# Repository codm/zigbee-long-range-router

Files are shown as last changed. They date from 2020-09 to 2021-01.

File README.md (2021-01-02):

# cod.m CC2530+CC2592 Long Range ZigBee Router
Here are the Eagle board files and schematic of cod.m's [Zigbee Long Range Router](https://shop.codm.de/automation/zigbee/23/zigbee-cc2530-cc2592-long-range-router/repeater) based on EByte's E18-MS1PA1-IPX sporting an CC2530 combined with an CC2592 PA/LNA for range extension.

The corresponding eagle library for the EByte modules, including 3D models, can be found here: https://github.com/codm/eagle-libraries

You can buy a ready built router, including external antenna, 3D printed case and power supply at our webshop: [CC2530-CC2592 Long Range ZigBee Router](https://shop.codm.de/automation/zigbee/23/zigbee-cc2530-cc2592-long-range-router/repeater)

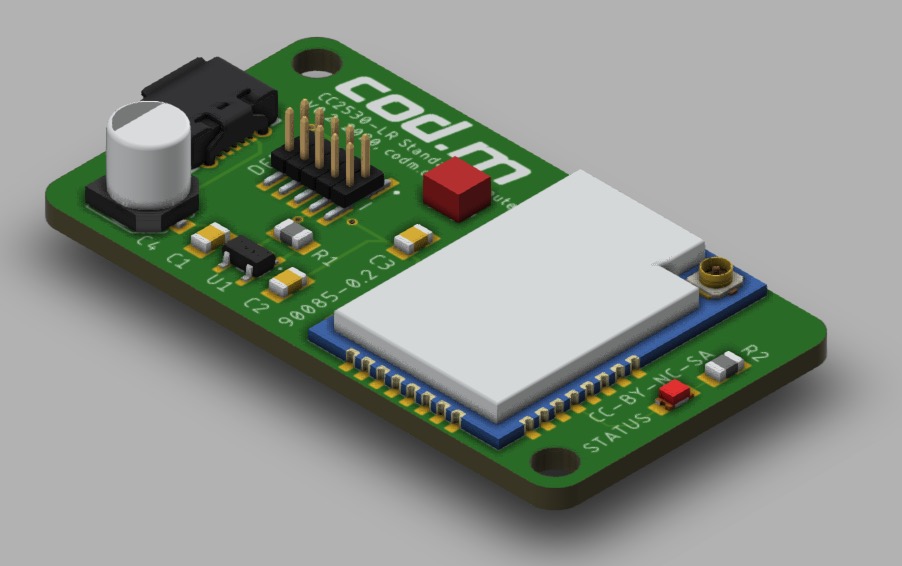
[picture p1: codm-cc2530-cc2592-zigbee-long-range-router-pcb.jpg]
cod.m ZigBee Long Range Router


# Case
We also designed a neat 3D printed case. The design files are available on Thingiverse: https://www.thingiverse.com/thing:4192704

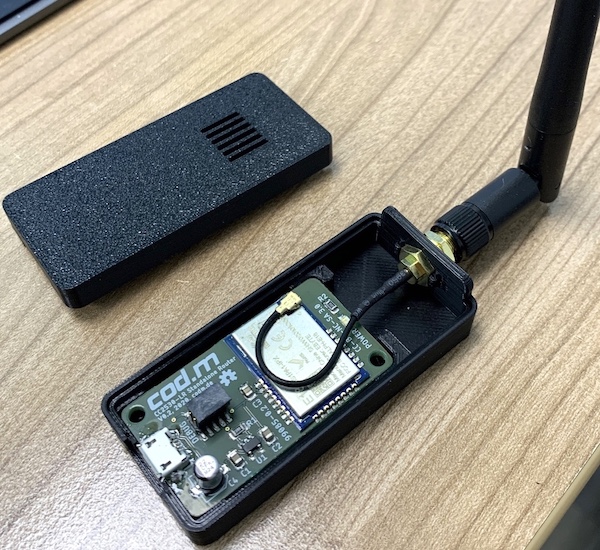
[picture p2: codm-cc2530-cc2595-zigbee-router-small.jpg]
cod.m ZigBee Long Range Router in Case


# Firmware
Thanks to https://ptvo.info and his [configurable ZigBee Firmware](https://ptvo.info/zigbee-switch-configurable-firmware-v2-210/), we've built our own version of the firmware - based on Z-Stack 1.2 - to make use of the onboard LED.

See zigbee2mqtt's FAQ for more info on how to use ZigBee routers and expand your current ZigBee mesh: https://www.zigbee2mqtt.io/information/FAQ.html#i-read-that-zigbee2mqtt-has-a-limit-of-20-devices-is-this-true

## Upgrading
You can flash the module with a another/new firmware using an CC-Debugger from TI, which is also used for the common CC2531-USB-Sticks. The pin header on the top has the same layout.

# License
[CC-BY-SA-NC 3.0](https://creativecommons.org/licenses/by-nc-sa/3.0/de/)

cod.m GmbH, Patrik Mayer, 2020

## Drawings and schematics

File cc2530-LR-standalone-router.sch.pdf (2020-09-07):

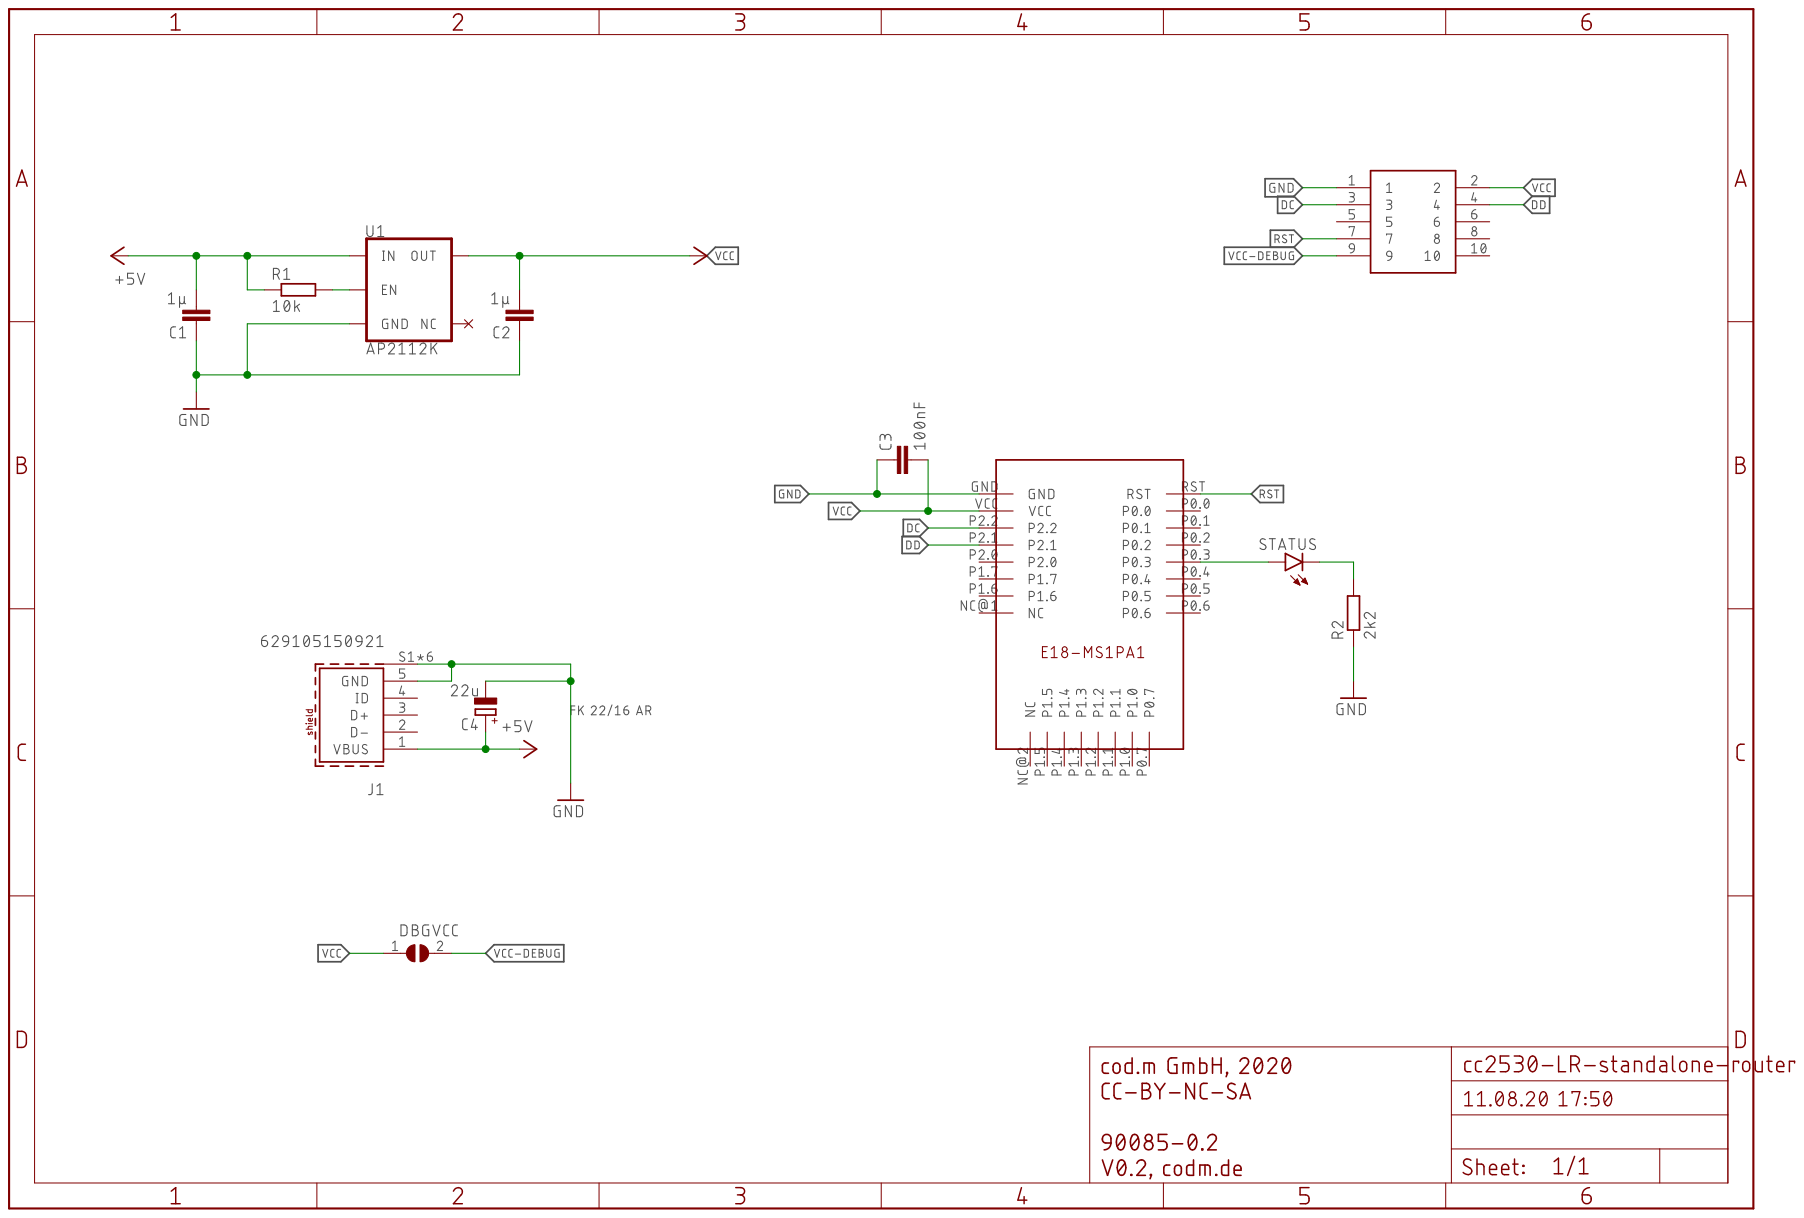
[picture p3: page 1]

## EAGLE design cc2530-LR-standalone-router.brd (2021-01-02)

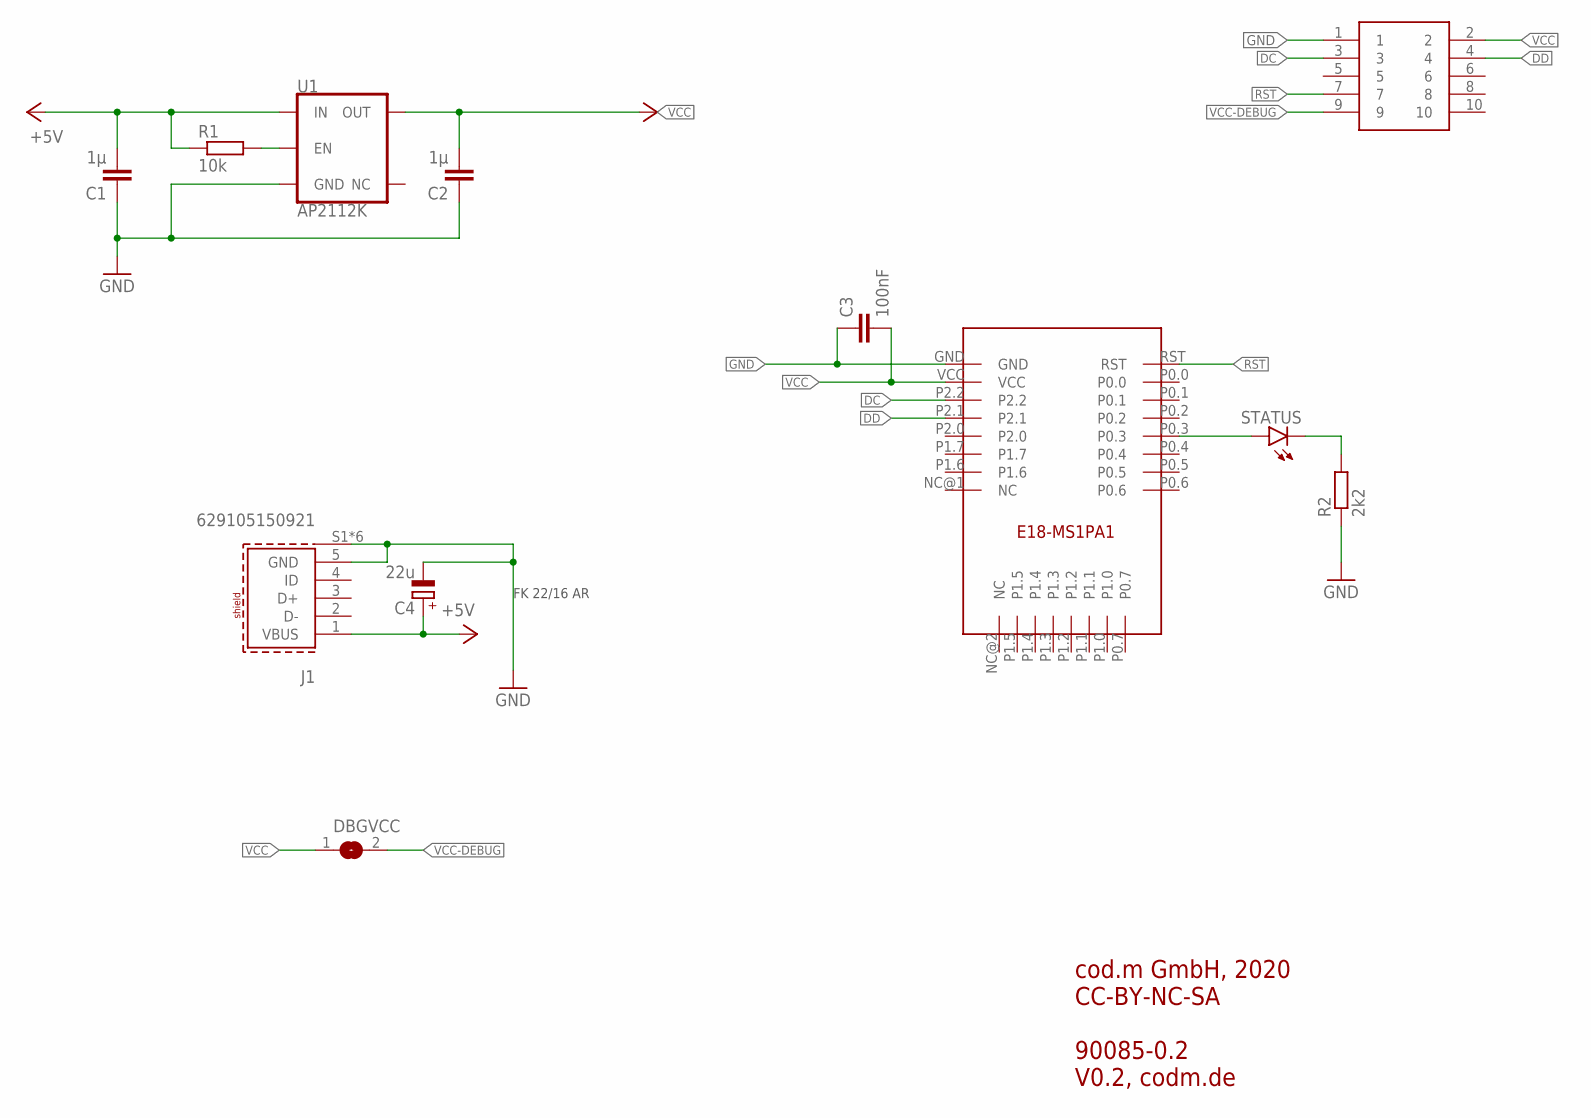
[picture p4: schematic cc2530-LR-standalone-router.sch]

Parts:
C1, C2: 1µ; C0805
C3: 100nF; C0805
C4: 22u; PANASONIC_C
DBGVCC: SJ
DEBUG: 20021121-00010C4LF; 2002112100010C4LF
J1: 629105150921
R1: 10k; R0805
R2: 2k2; R0805
STATUS: LEDCHIPLED_0805; CHIPLED_0805
U1: AP2112K; SOT23-5
U$5: E18-MS1PA1IPX; E18-MS1PA1-IPX

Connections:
+5V: C1.2, C4.+, J1.1 (VBUS), R1.1, U1.1 (IN)
DC: DEBUG.3, U$5.P2.2
DD: DEBUG.4, U$5.P2.1
GND: C1.1, C2.1, C3.1, C4.-, DEBUG.1, J1.5 (GND), J1.S1 (SHIELD), J1.S2 (SHIELD), J1.S3 (SHIELD), J1.S4 (SHIELD), J1.S5 (SHIELD), J1.S6 (SHIELD), R2.1, U1.2 (GND), U$5.GND
unnamed: R1.2, U1.3 (EN)
unnamed: R2.2, STATUS.C
unnamed: STATUS.A, U$5.P0.3
RST: DEBUG.7, U$5.RST
VCC: C2.2, C3.2, DBGVCC.1, DEBUG.2, U1.5 (OUT), U$5.VCC
VCC-DEBUG: DBGVCC.2, DEBUG.9

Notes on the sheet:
cod.m GmbH, 2020 CC-BY-NC-SA 90085-0.2 V0.2, codm.de
FK 22/16 AR

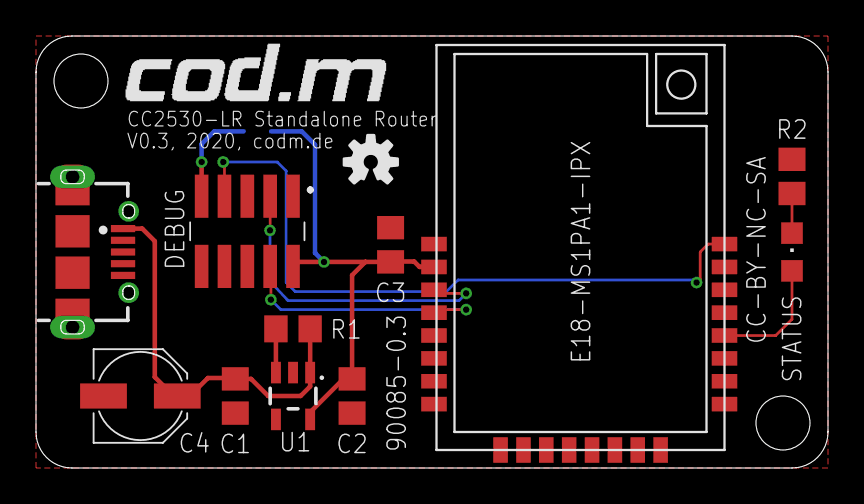
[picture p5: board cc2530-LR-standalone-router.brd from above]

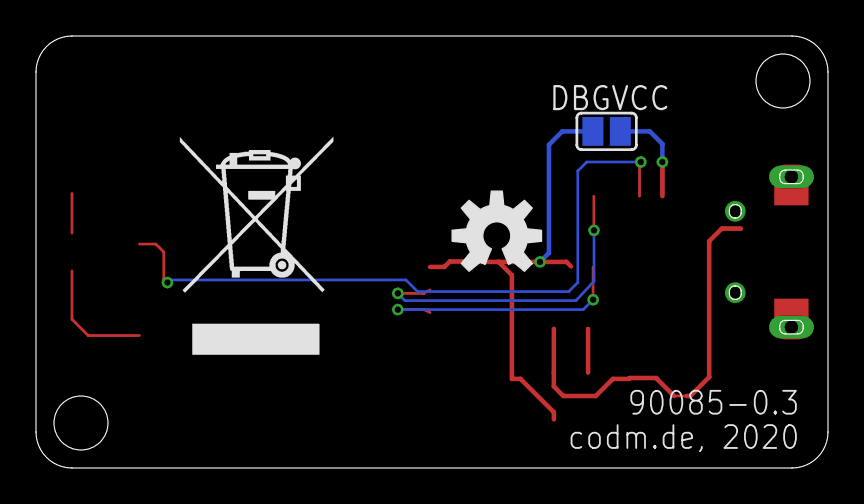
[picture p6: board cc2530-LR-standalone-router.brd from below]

Board: 2 copper layers, 44.0 x 24.0 mm, 16 parts (3 on the bottom side), 10 nets.

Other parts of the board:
U$1: WEEE-LOGO-8MM
U$2: CODM-LOGO
U$3: OSHW-LOGO-M
U$4: OSHW-LOGO-S

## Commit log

2020-09-07 first official release, V0.2
    [cc2530-LR-standalone-router.brd, cc2530-LR-standalone-router.sch]
2020-09-07 renamed schematics pdf
2021-01-02 bigger pads for e18-ms1pa1-ipx
    [cc2530-LR-standalone-router.brd, cc2530-LR-standalone-router.sch]
2021-01-02 minor rerouting
    [cc2530-LR-standalone-router.brd]

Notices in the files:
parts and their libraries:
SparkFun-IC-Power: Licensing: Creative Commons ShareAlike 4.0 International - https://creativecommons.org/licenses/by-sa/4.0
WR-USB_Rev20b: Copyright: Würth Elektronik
